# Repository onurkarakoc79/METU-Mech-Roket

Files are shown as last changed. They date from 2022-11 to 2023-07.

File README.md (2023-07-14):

# METU Mech Rocket Team Electronic Cards and Codes
This repository contains the electronic codes and card designs for the METU Mech Rocket Team's rocket system. The system consists of two card designs, each equipped with an Arduino Due controller.

## Communication Card
The first Arduino Due is responsible for communication and utilizes the following modules:

SX1262 LoRa module
SIM800L module
CH376S USB module
The communication card enables data transfer with the ground station. The SX1262 LoRa module and SIM800L module are used for wireless communication, while the CH376S USB module handles data storage to a USB device.

## Processor Card
The second Arduino Due is responsible for data processing and incorporates the following components:

BME280 sensor
Dallas temperature sensor
BMP180 sensor
NEO M8N GPS module
Parachute opening system (controlled by a servo and a transistor that fires the gas tank)
The processor card collects data related to humidity, temperature, altitude, and absolute location. It supports two sensors for each type of data, such as BME280 and BMP180. The collected data is processed using a Kalman filter algorithm for improved accuracy. The processed data is then transferred to the communication card via serial communication.

## Card Designs
This repository also includes the necessary files for the card designs. The provided KiCad files contain the card designs and necessary footprints. To use the designs, add the footprint files to KiCad in the appropriate manner. The card designs have been configured for use with either Arduino Due or Arduino Mega Due, based on the pin configuration.

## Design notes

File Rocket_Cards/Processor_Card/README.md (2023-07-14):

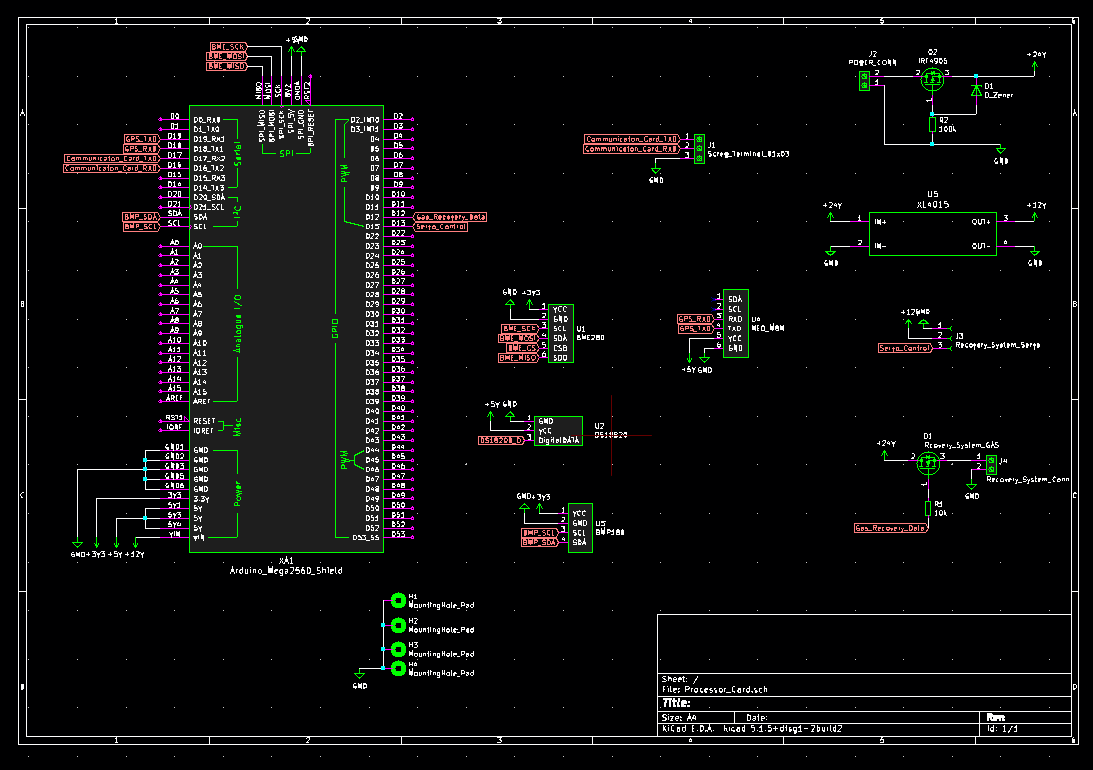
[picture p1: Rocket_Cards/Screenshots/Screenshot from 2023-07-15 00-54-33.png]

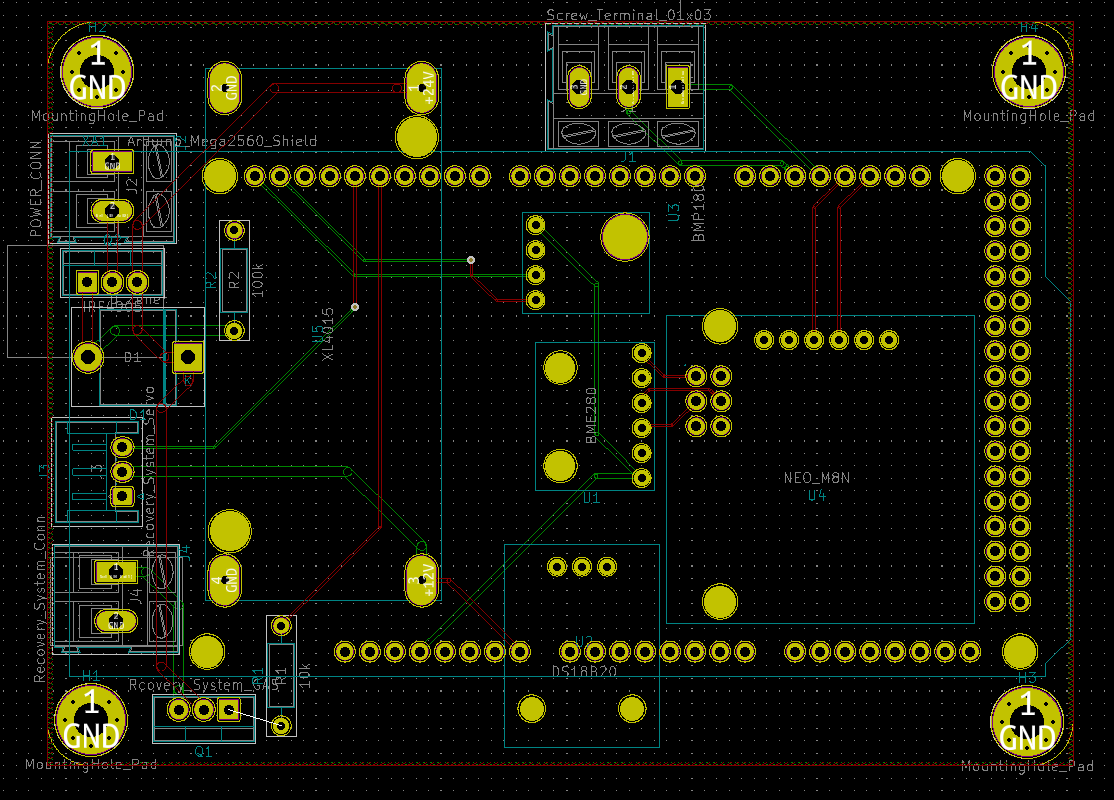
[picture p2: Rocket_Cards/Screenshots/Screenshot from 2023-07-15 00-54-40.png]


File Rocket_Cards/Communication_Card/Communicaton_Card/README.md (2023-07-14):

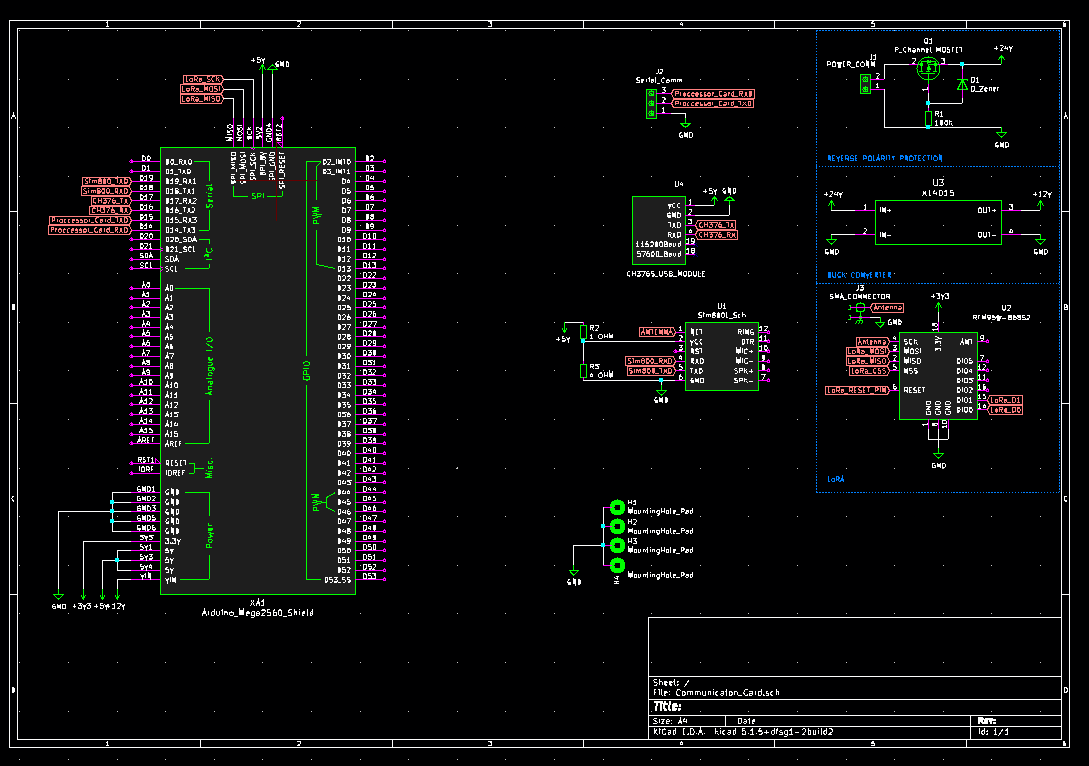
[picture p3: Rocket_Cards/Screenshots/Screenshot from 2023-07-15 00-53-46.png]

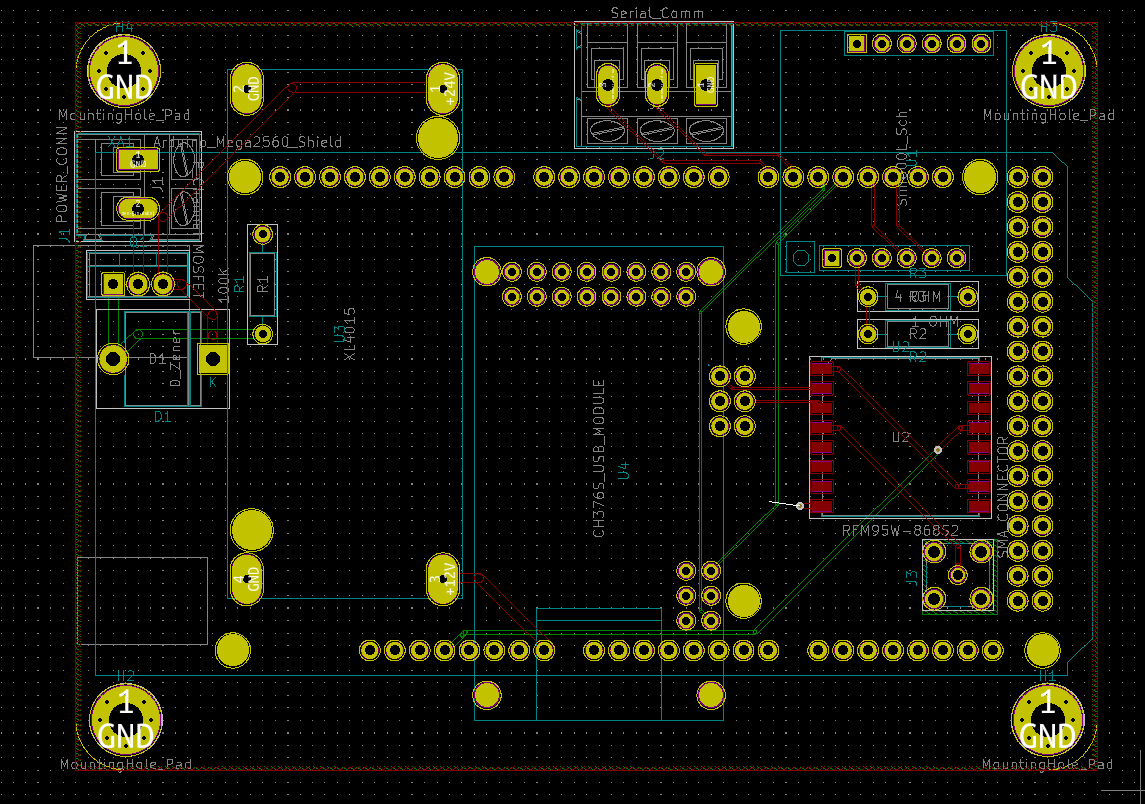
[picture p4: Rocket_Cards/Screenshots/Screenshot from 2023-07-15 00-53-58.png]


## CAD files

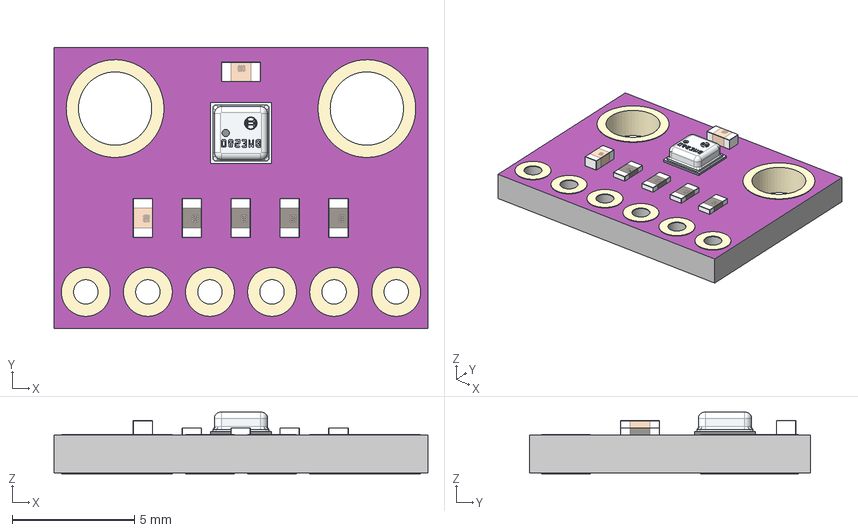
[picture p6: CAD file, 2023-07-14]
Rocket_Cards/Footprints/BME280/STEP/gy-bme280-6-pin-version-1.snapshot.2/GY-BME/P280, 6-PIN-Version v4.step
15.3 x 11.5 x 2.52 mm
Komponente1
Komponente2
Komponente3
Komponente4
Komponente5
Komponente6
Komponente7
Komponente8
Beschriftung
C0603 x 2
R0603 x 4
BME280

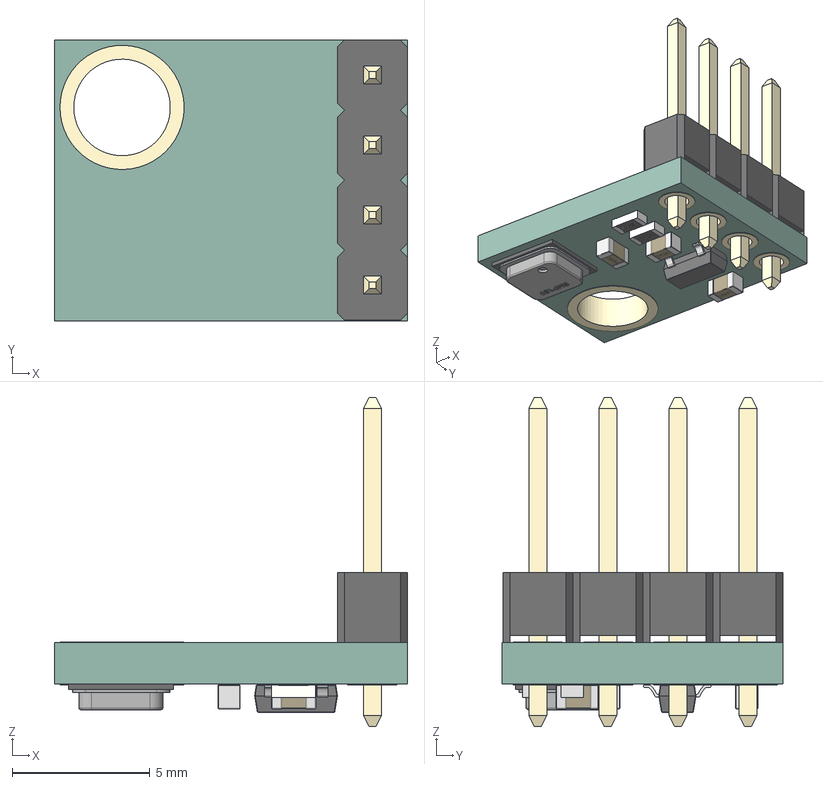
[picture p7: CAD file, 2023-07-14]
Rocket_Cards/Footprints/BMP180/STEP/bmp180-breakout-board-1.snapshot.2/BMP180 Breakout.step
12.8 x 10.2 x 11.9 mm
r-smd-0603 x 2
c-smd-0603 x 3
PinHeader
SOT23SMD v1
BMP180

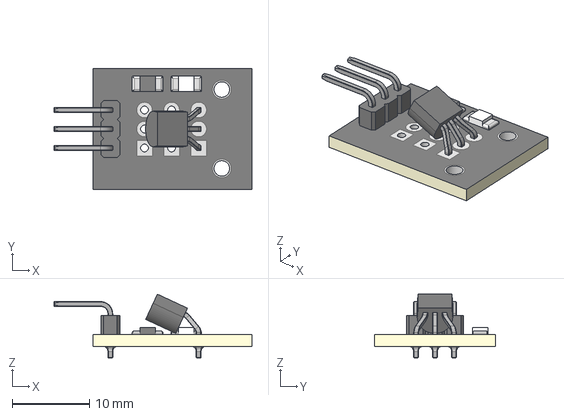
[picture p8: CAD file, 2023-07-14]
Rocket_Cards/Footprints/DS18B_Temp/STEP/temperature-sensor-module-joy-it-ky-001-ds18b20-1.snapshot.3/Temperatursensor.stp
25.6 x 15.7 x 8.24 mm

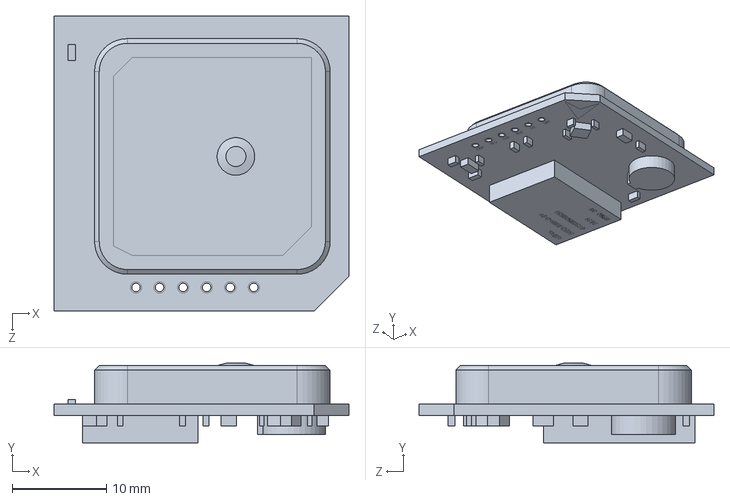
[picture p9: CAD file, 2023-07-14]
Rocket_Cards/Footprints/Neo_M8N/STEP/gps-ublox-neo-m8n-0-01-1.snapshot.1/Модуль GPS Ublox NEO-M8N-0-01.SLDPRT
31.3 x 8.44 x 31.3 mm

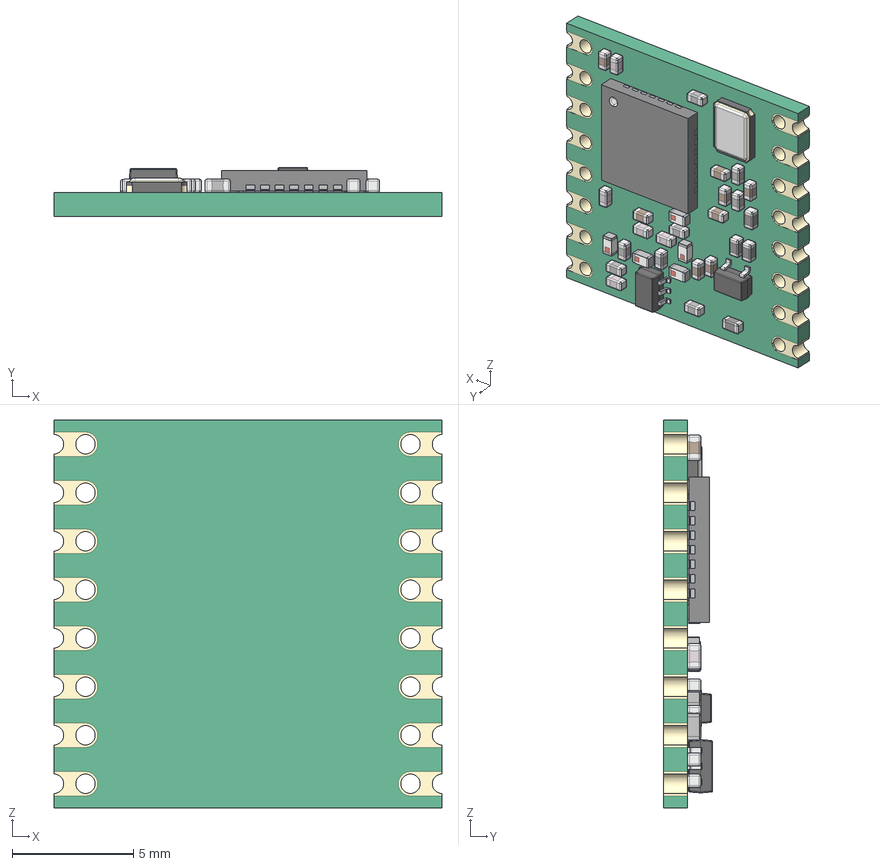
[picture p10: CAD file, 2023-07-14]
Rocket_Cards/Footprints/RFM95 STEP/rfm95-lora-radio-module-1.snapshot.1/RFM95 LoRa v15.step
16.0 x 2.04 x 16.0 mm
QFN 28
SMD Crystal
CAP 0403 x 8
CAP Ceramic 0403 x 8
Res 0403 x 4
CAP ML 0403 x 5
SOT-323
Inductor SMD 0403 x 5
SOT-363

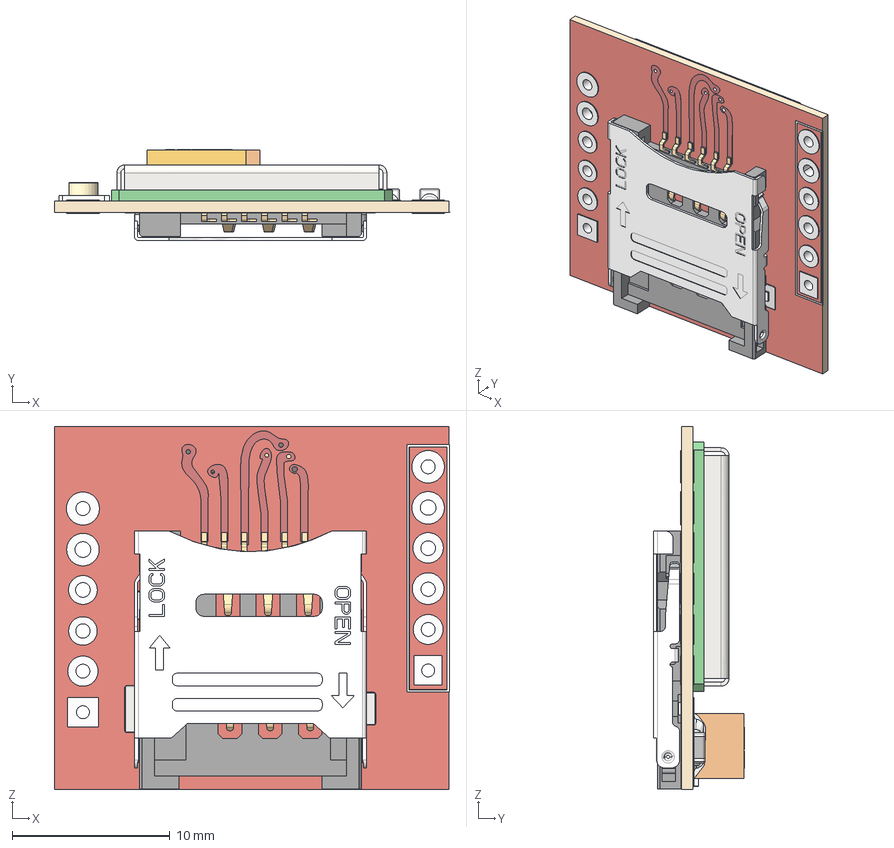
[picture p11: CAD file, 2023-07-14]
Rocket_Cards/Footprints/SIM800L-Core-Module-KiCad-Footprint-main/SIM800L v10.step
25.0 x 5.77 x 23.0 mm
PCB
Cage
CH03-HB

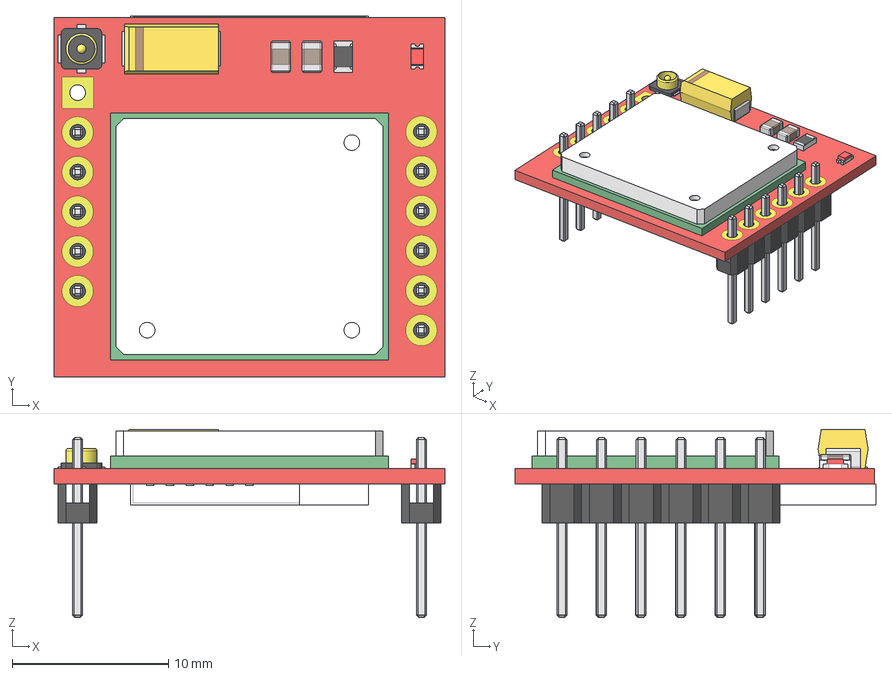
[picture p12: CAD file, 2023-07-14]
Rocket_Cards/Footprints/SIM800L-Core-Module-KiCad-Footprint-main/STEP/sim800l-9.snapshot.5/SIM800L.step
25.0 x 23.1 x 12.0 mm

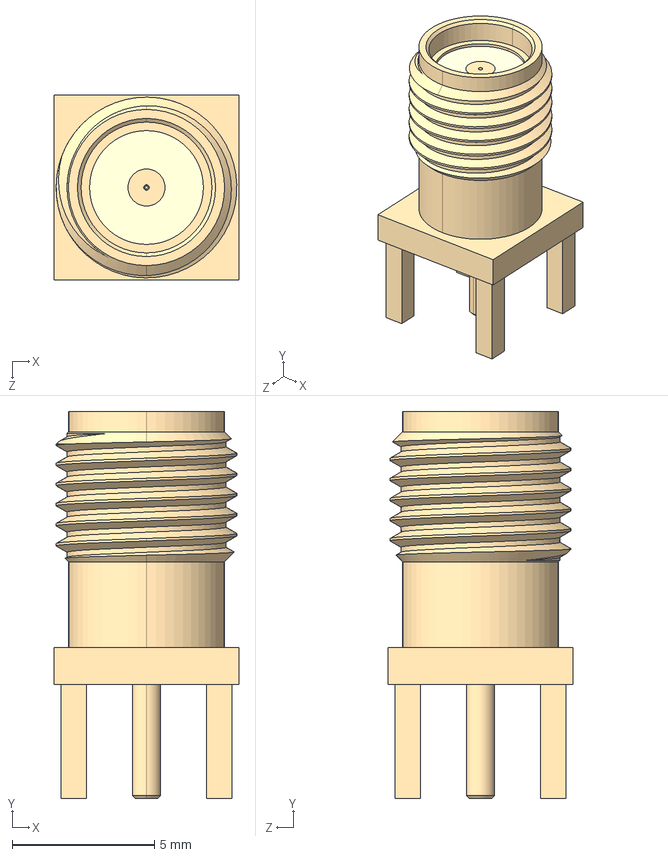
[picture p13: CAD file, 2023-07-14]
Rocket_Cards/Footprints/SMA_CONN/SMA_CONNECTOR (3)/SMA_CONNECTOR.step
6.50 x 13.6 x 6.50 mm

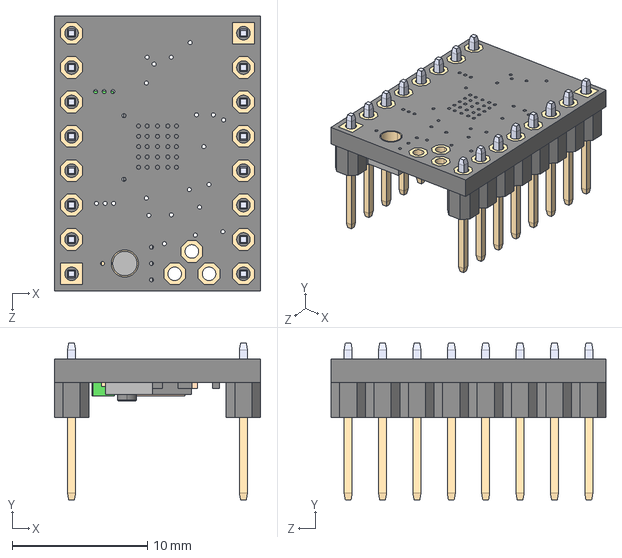
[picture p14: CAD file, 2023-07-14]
Rocket_Cards/Footprints/TMC2208_SILENTSTEPSTICK/TMC2208_SILENTSTEPSTICK.step
15.2 x 11.6 x 20.3 mm

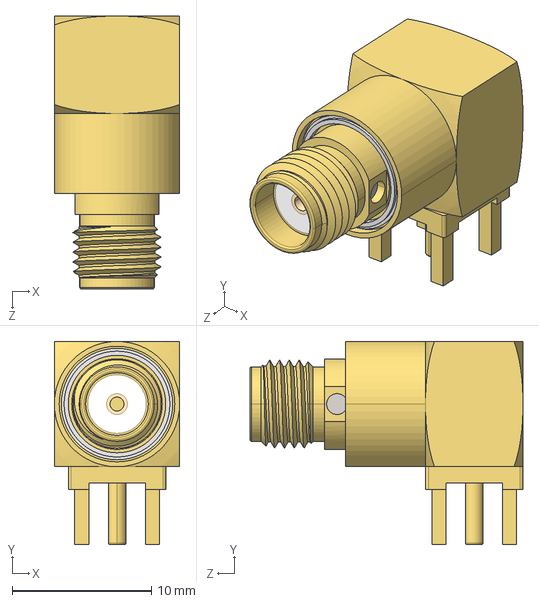
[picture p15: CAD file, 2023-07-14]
Rocket_Cards/Footprints/SMA_CONN/STEP/right-angle-sma-female-rotary-joint-pcb-mount-connector-1.snapshot.2/BM61276.STEP
9.00 x 14.6 x 19.6 mm

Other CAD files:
Rocket_Cards/Footprints/BME280/STEP/gy-bme280-6-pin-version-1.snapshot.2/GY-BME/P280, 6-PIN-Version v4.f3d
Rocket_Cards/Footprints/BMP180/STEP/bmp180-breakout-board-1.snapshot.2/BMP180 Breakout.f3d
Rocket_Cards/Footprints/DS18B_Temp/STEP/temperature-sensor-module-joy-it-ky-001-ds18b20-1.snapshot.3/Temperatursensor.igs
Rocket_Cards/Footprints/DS18B_Temp/STEP/temperature-sensor-module-joy-it-ky-001-ds18b20-1.snapshot.3/Temperatursensor.ipt

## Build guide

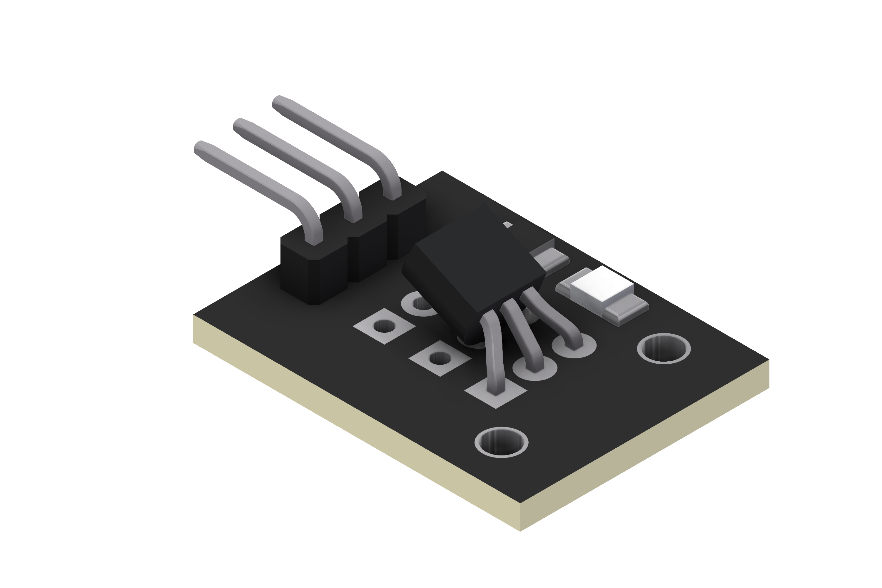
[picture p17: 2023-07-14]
Rocket_Cards/Footprints/DS18B_Temp/STEP/temperature-sensor-module-joy-it-ky-001-ds18b20-1.snapshot.3/Temperatursensor.png

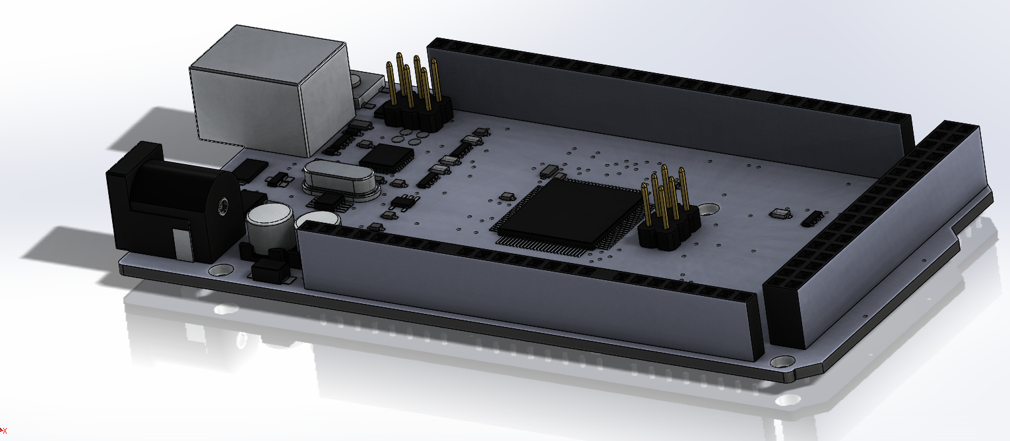
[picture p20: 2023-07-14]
Rocket_Cards/Footprints/arduino-kicad-library-master/STEP/arduino-mega-due-1.snapshot.2/Screenshot_11.png

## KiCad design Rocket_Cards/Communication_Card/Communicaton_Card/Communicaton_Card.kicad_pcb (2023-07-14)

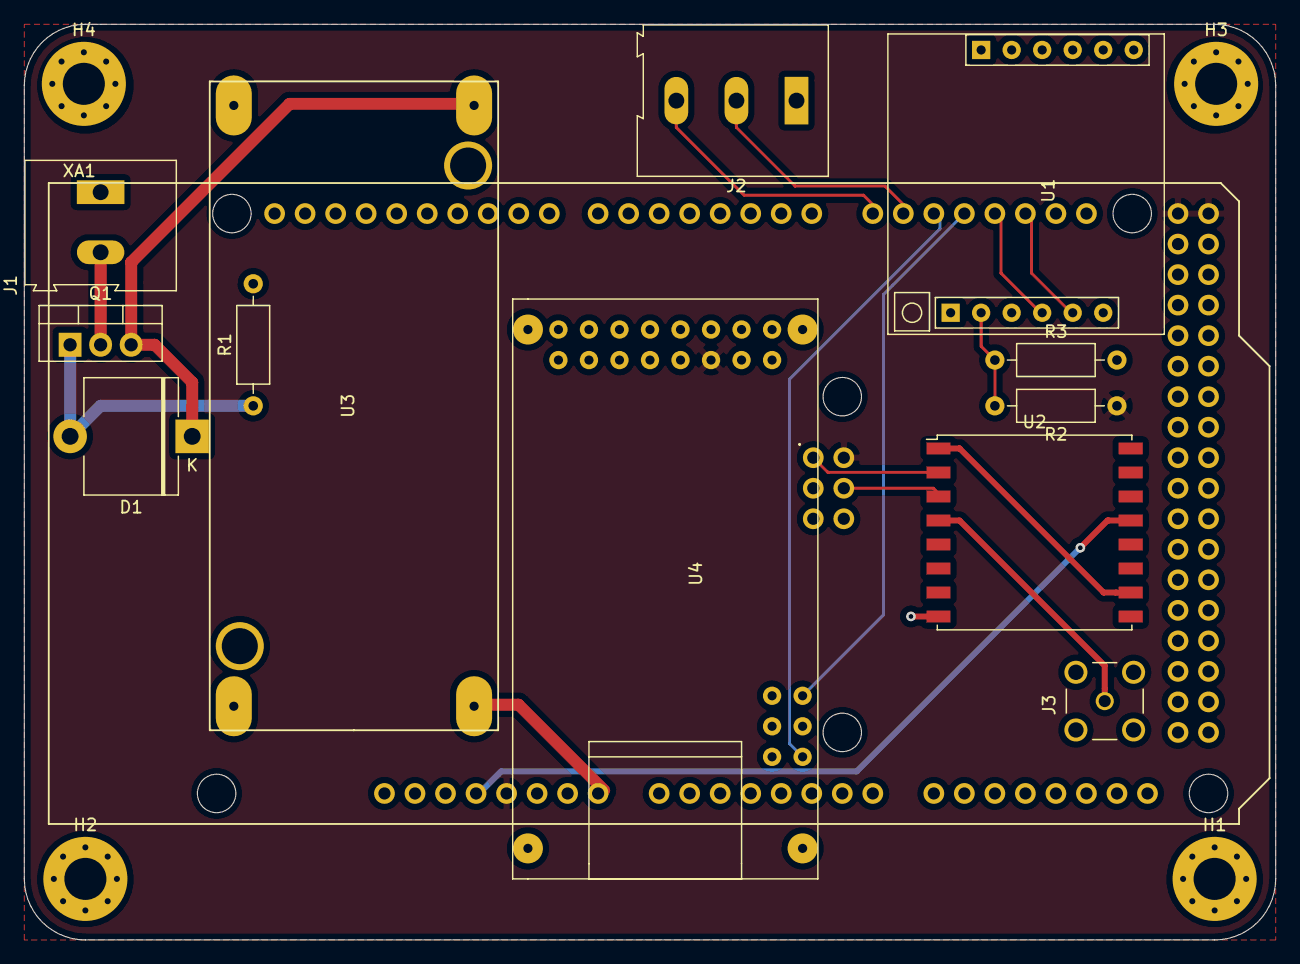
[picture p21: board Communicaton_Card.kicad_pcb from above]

Board: 2 copper layers, 104.1 x 76.2 mm, 17 parts (0 on the bottom side), 18 nets.

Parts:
D1: D_Zener; D_5KP_P10.16mm_Horizontal
H1, H2, H3, H4: MountingHole_Pad; MountingHole_3.5mm_Pad_Via
J1: POWER_CONN; TerminalBlock_Altech_AK300-2_P5.00mm
J2: Serial_Comm; TerminalBlock_Altech_AK300-3_P5.00mm
J3: SMA_CONNECTOR; LPRS_SMA_CONNECTOR
Q1: P_Channel MOSFET; TO-220-3_Vertical
R1: 100K; R_Axial_DIN0207_L6.3mm_D2.5mm_P10.16mm_Horizontal
R2: 1 OHM; R_Axial_DIN0207_L6.3mm_D2.5mm_P10.16mm_Horizontal
R3: 4 OHM; R_Axial_DIN0207_L6.3mm_D2.5mm_P10.16mm_Horizontal
U1: Sim800L_Sch; Sim800L
U2: RFM95W-868S2; HOPERF_RFM9XW_SMD
U3: XL4015; XL4015_Converter
U4: CH376S_USB_MODULE; CH376_USB_Foot
XA1: Arduino_Mega2560_Shield

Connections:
+3V3: U2.13, XA1.3V3
+5V: R2.1, U4.1, XA1.5V1, XA1.5V2, XA1.5V3, XA1.5V4
+12V: U3.3, XA1.VIN
+24V: D1.1, Q1.3, U3.1
Antenna: J3.1, U2.4
CH376_RX: U4.4, XA1.D16
CH376_TX: U4.3, XA1.D17
GND: H1.1, H2.1, H3.1, H4.1, J1.1, J2.1, J3.G1, J3.G2, J3.G3, J3.G4, R1.2, R3.2, U1.6, U2.8, U3.2, U3.4, U4.2, XA1.GND1, XA1.GND2, XA1.GND3, XA1.GND4, XA1.GND5, XA1.GND6
LoRa_MISO: U2.2, XA1.MISO
LoRa_MOSI: U2.3, XA1.MOSI
unnamed: D1.2, Q1.1, R1.1
unnamed: J1.2, Q1.2
unnamed: R2.2, R3.1, U1.2
unnamed: U2.1, U2.10
Proccessor_Card_RXD: J2.3, XA1.D14
Proccessor_Card_TXD: J2.2, XA1.D15
Sim800_RXD: U1.4, XA1.D18
Sim800_TXD: U1.5, XA1.D19

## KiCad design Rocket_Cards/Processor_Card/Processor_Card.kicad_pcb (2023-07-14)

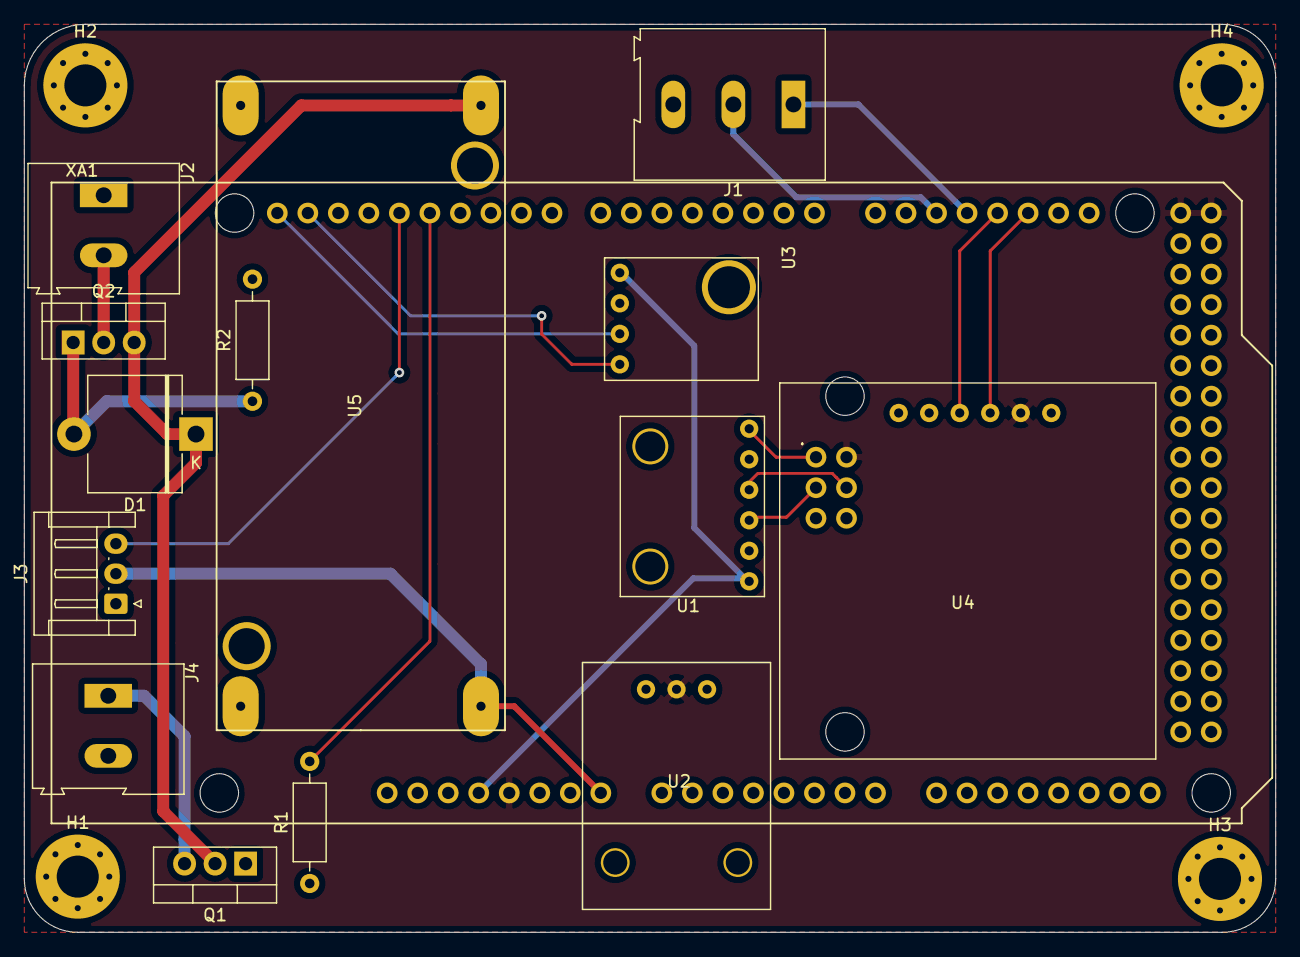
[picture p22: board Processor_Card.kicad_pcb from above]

Board: 2 copper layers, 104.1 x 75.6 mm, 19 parts (0 on the bottom side), 20 nets.

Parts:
D1: D_Zener; D_5KP_P10.16mm_Horizontal
H1, H2, H3, H4: MountingHole_Pad; MountingHole_3.5mm_Pad_Via
J1: Screw_Terminal_01x03; TerminalBlock_Altech_AK300-3_P5.00mm
J2: POWER_CONN; TerminalBlock_Altech_AK300-2_P5.00mm
J3: Recovery_System_Servo; JST_EH_S3B-EH_1x03_P2.50mm_Horizontal
J4: Recovery_System_Conn; TerminalBlock_Altech_AK300-2_P5.00mm
Q1: Rcovery_System_GAS; TO-220-3_Vertical
Q2: IRF4905; TO-220-3_Vertical
R1: 10k; R_Axial_DIN0207_L6.3mm_D2.5mm_P10.16mm_Horizontal
R2: 100k; R_Axial_DIN0207_L6.3mm_D2.5mm_P10.16mm_Horizontal
U1: BME280; BME280_3.3
U2: DS18B20
U3: BMP180
U4: NEO_M8N; Neo_M8N
U5: XL4015; XL4015_Converter
XA1: Arduino_Mega2560_Shield

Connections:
+3V3: U1.1, U3.1, XA1.3V3
+5V: U2.2, U4.5, XA1.5V1, XA1.5V2, XA1.5V3, XA1.5V4
+12V: J3.2, U5.3, XA1.VIN
+24V: D1.1, Q1.2, Q2.3, U5.1
BME_MISO: U1.6, XA1.MISO
BME_MOSI: U1.4, XA1.MOSI
BME_SCK: U1.3, XA1.SCK
BMP_SCL: U3.3, XA1.SCL
BMP_SDA: U3.4, XA1.SDA
Communicaton_Card_RXD: J1.2, XA1.D16
Communicaton_Card_TXD: J1.1, XA1.D17
GND: H1.1, H2.1, H3.1, H4.1, J1.3, J2.1, J3.1, J4.2, R2.2, U1.2, U2.1, U3.2, U4.6, U5.2, U5.4, XA1.GND1, XA1.GND2, XA1.GND3, XA1.GND4, XA1.GND5, XA1.GND6
GPS_RXD: U4.3, XA1.D18
GPS_TXD: U4.4, XA1.D19
Gas_Recovery_Data: R1.2, XA1.D12
unnamed: D1.2, Q2.1, R2.1
unnamed: J2.2, Q2.2
unnamed: J4.1, Q1.3
unnamed: Q1.1, R1.1
Servo_Control: J3.3, XA1.D13

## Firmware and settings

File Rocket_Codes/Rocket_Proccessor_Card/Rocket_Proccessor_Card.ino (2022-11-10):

#include <Wire.h>
#include <SPI.h>
#include <SoftSPIB.h>
#include <Adafruit_Sensor.h>
#include <Adafruit_BME280.h>
#include <HoneyWell_Pressure.h>
#include <TinyGPS++.h>
#include <MPU6050.h>
#include <I2Cdev.h>
#include <SimpleKalmanFilter.h>
#include <OneWire.h>
#include <DallasTemperature.h>




////////////////////////////////////////////////////////////////////DALLAS TEMPERTURE DEFINES BEGINS////////////////////////////////////////////////////////////////////////////////


static const uint8_t ONE_WIRE_BUS=47;
OneWire oneWire(ONE_WIRE_BUS);
DallasTemperature sensors(&oneWire);
DeviceAddress insideThermometer;
float dallasTemp;
float absoluteTemp;


////////////////////////////////////////////////////////////////////DALLAS TEMPERTURE DEFINES ENDS////////////////////////////////////////////////////////////////////////////////








//////////////////////////////////////////////////////////////////////////////GPS DEFINES START///////////////////////////////////////////////////////////////////////////////////


TinyGPSPlus gps;
static const uint32_t GPSBaud = 9600;
String gpsMessage="";


////////////////////////////////////////////////////////////////////////////////GPS DEFINES END///////////////////////////////////////////////////////////////////////////////////






///////////////////////////////////////////////////////////////////////PARACHUTE DEFINES STARTS///////////////////////////////////////////////////////////////////////////////////


static const int parachutePin=8;
static const int dt=1000;
static const int buzzerPin=37;
static const int ledPin=6;
static const int baloonPin=7;
bool isParachuteOpen=false;
unsigned long velocityTimer=millis();
int pastAltitude;
float velocity;
float threshold_Velocity_Parachute=40.0;
float threshold_Altitude=3000.0;
float threshold_Velocity_Baloon=70.0;
float maxAltitude=30000.0;
bool delayTimes(unsigned long *pasttime,int ms);
bool isOpen=false;
bool isBaloonCut=false;
int cutRopeCounter=0;
float pastVelocity=0;


/////////////////////////////////////////////////////////////////////////PARACHUTE DEFINES ENDS///////////////////////////////////////////////////////////////////////////////////






///////////////////////////////////////////////////////////////////////KALMAN FILTER DEFINES STARTS////////////////////////////////////////////////////////////////////////////////


SimpleKalmanFilter bmeKalman(1.0,1.0,0.01); //SimpleKalmanFilter(e_mea, e_est, q); e_mea: Measurement Uncertainty ,e_est: Estimation Uncertainty ,q: Process Noise
SimpleKalmanFilter honeywellKalman(0.1,1.0,0.03);
const long SERIAL_REFRESH_TIME=100;
long refresh_time;
bool bme_Error_Changed=false;
float absoluteAltitude;
float absolutePressure;


//////////////////////////////////////////////////////////////////////////KALMAN FILTER DEFINES ENDS//////////////////////////////////////////////////////////////////////////////






////////////////////////////////////////////////////////////////////////BME SPI DEFINES STARTS////////////////////////////////////////////////////////////////////////////////////


static const uint8_t BME_SCK=13;    // SCL to Pin 13 Arduino UNO
static const uint8_t BME_MISO=12;   // SDO to Pin 12
static const uint8_t BME_MOSI=11;   // SDA to Pin 11 
static const uint8_t BME_CS=5;     // CSB to Pin 10
static const uint8_t BME_Addresses=0x77;
static const float SEALEVELPRESSURE_HPA=1013.25;
Adafruit_BME280 bme(BME_CS); // hardware SPI
float bmeData[4]; //temp,pres,alt,hum
bool bmeEnable=true;
void bmeReadData(float *bmeDatas);
void bmePrintData(float *bmeDatas);
void bmeBegin(uint8_t addr);


////////////////////////////////////////////////////////////////////////////BME SPI DEFINES ENDS//////////////////////////////////////////////////////////////////////////////////






////////////////////////////////////////////////////////////////////////HONEYWELL PRESSURE DEFINES STARTS/////////////////////////////////////////////////////////////////////////


static const uint8_t HONEY_RESET_PIN=4;
unsigned long honeywellTimer=millis();
bool honeyEnable=true;
HoneyWell honey;
void honeyPrintData();
void checkHoneyData();


///////////////////////////////////////////////////////////////////////////// HONEYWELL PRESSURE DEFINES END//////////////////////////////////////////////////////////////////////






//////////////////////////////////////////////////////////////////////////SERIAL CONNECTION DEFINES STARTS////////////////////////////////////////////////////////////////////////


static const uint32_t MEGABaud=9600;
String message;
char termChar='#';
char c=' ';
bool haveNewData=false;
void readMessages();
void processNewData();
String Message;


///////////////////////////////////////////////////////////////////////////SERIAL CONNECTION DEFINES ENDS/////////////////////////////////////////////////////////////////////////





















void setup() {
  // put your setup code here, to run once:
  Serial.begin(9600);
  Serial1.begin(GPSBaud);
  Serial3.begin(MEGABaud);
  
  Wire.begin();
  
  pinMode(ONE_WIRE_BUS,INPUT_PULLUP);
  pinMode(HONEY_RESET_PIN,OUTPUT);
  digitalWrite(HONEY_RESET_PIN,HIGH);
  honey.begin();

  pinMode(buzzerPin,OUTPUT);
  pinMode(ledPin,OUTPUT);
  pinMode(baloonPin,OUTPUT);
  digitalWrite(buzzerPin,LOW);
  digitalWrite(ledPin,LOW);
  digitalWrite(baloonPin,LOW);
  bmeBegin(BME_Addresses);
  estimateAltitude();
  pastAltitude=absoluteAltitude;
  
  DallasBegin();
  
  delay(1000);
}


void loop() {
  // put your main code here, to run repeatedly:
  //if(gps.failedChecksum())
  GPSCreateMessage();
  
  changeBMEaccuracy();
  bmeReadData(bmeData);
  
  
  calculateAbsoluteTemp();
  
  
  honey.takePressure();
  Serial.print(honey.pressure);
  Serial.print(" ");
  honey.takeAltitude(SEALEVELPRESSURE_HPA);
  honeyPrintData();
  checkHoneyData();
  
  estimateAltitude();
  estimatePressure();
  
   if(!isOpen){ 
      calculateVelocity();
      if(!isBaloonCut){
        cutTheBaloon();
      }
      else{
        checkFreeFaling();
      }
  }
  if(isParachuteOpen){
    openLedAndBuzzer();
  }
  
  sendMessages();
  
  delay(500);
}





















///////////////////////////////////////////////////////////////////////////GPS FUNCTIONS START///////////////////////////////////////////////////////////////////////////////////


static void GPSCreateMessage(){

  static const double LONDON_LAT = 41.508131, LONDON_LON = 27.128002;
  if (millis() > 5000 && gps.charsProcessed() < 10)
    gpsMessage+="No GPS data received: check wiring";
  
  else{
    gpsMessage+="Satellites: ";
    if(gps.satellites.isValid()){
      gpsMessage+=(String)gps.satellites.value()+" "; 
    }
    else{
      gpsMessage+="**** ";
    }
    gpsMessage+="Location: " ;
    if(gps.location.isValid()){
      gpsMessage+=(String)gps.location.lat()+" "+(String)gps.location.lng()+" ";
    }
    else{
      gpsMessage+="**** **** ";
    }
    gpsMessage+="Course: ";
    if(gps.course.isValid()){
      gpsMessage+=(String)gps.course.deg()+" ";
    }
    else{
      gpsMessage+="**** ";
    }
    gpsMessage+="Speed: ";
    if(gps.speed.isValid()){
      gpsMessage+=(String)gps.speed.kmph()+" ";
    }
    else{
      gpsMessage+="**** ";
    }
  }
  smartDelay(0);
}

static void smartDelay(unsigned long ms)
{
  unsigned long start = millis();
  do 
  {
    while (Serial1.available())  // due icin duzeldi 
      gps.encode(Serial1.read());// due icin duzeldi 
  } while (millis() - start < ms);
}


////////////////////////////////////////////////////////////////////////////GPS FUNCTIONS ENDS////////////////////////////////////////////////////////////////////////////////////






///////////////////////////////////////////////////////////////////////////BME FUNCTIONS START////////////////////////////////////////////////////////////////////////////////////

void bmeBegin(uint8_t addr){
  
  unsigned status;
  status=bme.begin(addr);
  
  if(!status){
      Serial.println("Could not find a valid BME280 sensor, check wiring, address, sensor ID!");
      Serial.print("SensorID was: 0x"); Serial.println(bme.sensorID(),16);
      Serial.print("        ID of 0xFF probably means a bad address, a BMP 180 or BMP 085\n");
      Serial.print("   ID of 0x56-0x58 represents a BMP 280,\n");
      Serial.print("        ID of 0x60 represents a BME 280.\n");
      Serial.print("        ID of 0x61 represents a BME 680.\n");
      while (1) delay(10);
  }
  else{
    Serial.println("BME Started successfully");
  }
}

void bmeReadData(float *bmeDatas){
    bmeDatas[0]=bme.readTemperature();
    if(honey.altitude>9000.0){
      bmeEnable=false;
    }
    else{ 
      bmeDatas[1]=bme.readPressure()/100.0F;
      bmeDatas[2]=bme.readAltitude(SEALEVELPRESSURE_HPA);
      bmeDatas[2]=bmeKalman.updateEstimate(bmeDatas[2]);
      bmeDatas[1]=bmeKalman.updateEstimate(bmeDatas[1]);
      bmeEnable=true;
    }
    bmeDatas[3]=bme.readHumidity();
}

void bmePrintData(float *bmeDatas){
    
    Serial.print("Temperature = ");
    Serial.print(bmeData[0]);
    Serial.println(" °C");

    Serial.print("Pressure = ");

    Serial.print(bmeData[1]);
    Serial.println(" hPa");
    Serial.print("Approx. Altitude = ");
    Serial.print(bmeData[2]);
    Serial.print(" m  ");

    Serial.print("Humidity = ");
    Serial.print(bmeData[3]);
    Serial.println(" %");

    Serial.println();
}

////////////////////////////////////////////////////////////////////////////BME FUNCTIONS END/////////////////////////////////////////////////////////////////////////////////////






//////////////////////////////////////////////////////////////////HONEYWELL PRESSURE FUNCTIONS START//////////////////////////////////////////////////////////////////////////////


void honeyPrintData(){
  
  float hpa=honey.convertTohPA();
  Serial.print(honey.altitude);
  Serial.print("  meter  ");
}

void checkHoneyData(){
  if(isnan(honey.altitude)){
    digitalWrite(HONEY_RESET_PIN,LOW);
    delayTimes(&honeywellTimer,10);
    digitalWrite(HONEY_RESET_PIN,HIGH);
    honeyEnable=false;
  }
  else{
    honeyEnable=true;
  }
}


/////////////////////////////////////////////////////////////////////HONEYWELL PRESSURE FUNCTIONS END/////////////////////////////////////////////////////////////////////////////






///////////////////////////////////////////////////////////////////////KALMAN FILTER FUNCTIONS STARTS/////////////////////////////////////////////////////////////////////////////


void changeBMEaccuracy(){
  if(absoluteTemp<0){
    bmeKalman.setMeasurementError(1.7);
    bme_Error_Changed=true;
  }
  else if(bme_Error_Changed==true && absoluteTemp>0){
    bmeKalman.setMeasurementError(1.0);
    bme_Error_Changed=false;
  }
  
}

void estimateAltitude(){
  honey.altitude=honeywellKalman.updateEstimate(honey.altitude);
  if(bmeEnable && honeyEnable){
    Serial.println("bacın");
     absoluteAltitude=(honey.altitude+bmeData[2])/2.0;
  }
  else if (!bmeEnable && honeyEnable){
    Serial.println("anan");
    absoluteAltitude=honey.altitude;
  }
  else{
    Serial.println("ninen");
    absoluteAltitude=bmeData[2];
  }
  
}

void estimatePressure(){
  honey.pressure=honey.convertTohPA();
  honey.pressure=honeywellKalman.updateEstimate(honey.pressure);
  if(bmeEnable && honeyEnable){
    absolutePressure=(honey.pressure+bmeData[1])/2.0;
  }
  else if(!bmeEnable && honeyEnable){
    absolutePressure=honey.pressure;
  }
  else{
    absolutePressure=bmeData[1];
  }
}


////////////////////////////////////////////////////////////////////////KALMAN FILTER FUNCTIONS END///////////////////////////////////////////////////////////////////////////////






///////////////////////////////////////////////////////////////////////SERIAL CONNECTION CODES STARTS/////////////////////////////////////////////////////////////////////////////


void readMessages(){
  
  if(Serial3.available()){
     c=Serial3.read();
     if(c!=termChar){
        message+=c;
     }
     else{
      message=""; //bura hatalı
      haveNewData=true;
     }
  }
}


String createMessagePackage(){
  String message="";
  message="Temperture: "+(String)absoluteTemp;
  message+=" Pressure: "+(String)absolutePressure;
  message+=" Humidity: "+(String)bmeData[3];
  message+=" Altitude: "+(String)absoluteAltitude;
  message+=" Velocity vertical: "+(String)velocity+" ";
  message+=gpsMessage;
  message+="\n";
  gpsMessage="";
  return message+'#';
}

void sendMessages(){
  Message=createMessagePackage(); 
  Serial3.print(Message);
}


///////////////////////////////////////////////////////////////////////SERIAL CONNECTION CODES ENDS///////////////////////////////////////////////////////////////////////////////









////////////////////////////////////////////////////////////////////////PARACHUTE FUSE CODE STARTS///////////////////////////////////////////////////////////////////////////////


bool delayTimes(unsigned long *pasttime,int ms){
  if(millis()-*pasttime>=ms){
    *pasttime=millis();
    return true;
  }
  else{
    return false;
  }
}

void calculateVelocity(){
   if(delayTimes(&velocityTimer,dt)){
    velocity=(absoluteAltitude-pastAltitude); 
    pastAltitude=absoluteAltitude;
  }
}

void checkFreeFaling(){
  if(velocity<0.0 && abs(velocity)>threshold_Velocity_Parachute && absoluteAltitude<threshold_Altitude){
    digitalWrite(parachutePin,HIGH);
    isParachuteOpen=true;
  }
}

void openLedAndBuzzer(){
  isOpen=true;
  //Serial.print(" LED HIGH");
  //Serial.println("  BUZZER HIGH");
  digitalWrite(ledPin,HIGH);
  digitalWrite(buzzerPin,HIGH);
}

void cutTheBaloon(){
  if(absoluteAltitude>maxAltitude || cutRopeCounter>5|| absoluteTemp<-40.0){
    digitalWrite(baloonPin,HIGH);
    isBaloonCut=true;
    
    /*Serial.println("         ");
    Serial.println("Baloon Ropes Cut");
    Serial.println("Baloon Ropes Cut");
    Serial.println("  ");*/
    
  }
  if(velocity!=pastVelocity){
      
    if(velocity<0.0 && abs(velocity)>threshold_Velocity_Baloon){
      cutRopeCounter++;
    }
    else{
      cutRopeCounter=0;
    }
    pastVelocity=velocity;
  }
 
}


///////////////////////////////////////////////////////////////////////////PARACHUTE FUSE CODE ENDS///////////////////////////////////////////////////////////////////////////////







////////////////////////////////////////////////////////////////////DALLAS TEMPERTURE FUNCTIONS BEGINS////////////////////////////////////////////////////////////////////////////

void calculateAbsoluteTemp(){
  sensors.requestTemperatures();
  dallasTemp= sensors.getTempC(insideThermometer);
  absoluteTemp=(dallasTemp+bmeData[0])/2.0;
}

void DallasBegin(){
  
  Serial.println("Dallas Temperature IC Control Library Demo");

  // locate devices on the bus
  Serial.print("Locating devices...");
  sensors.begin();
  Serial.print("Found ");
  Serial.print(sensors.getDeviceCount(), DEC);
  Serial.println(" devices.");

  // report parasite power requirements
  Serial.print("Parasite power is: "); 
  if (sensors.isParasitePowerMode()) Serial.println("ON");
  else Serial.println("OFF");
  
  
  if (!sensors.getAddress(insideThermometer, 0)) Serial.println("Unable to find address for Device 0"); 
  Serial.print("Device 0 Address: ");
  printAddress(insideThermometer);
  Serial.println();

  // set the resolution to 9 bit (Each Dallas/Maxim device is capable of several different resolutions)
  sensors.setResolution(insideThermometer, 9);
 
  Serial.print("Device 0 Resolution: ");
  Serial.print(sensors.getResolution(insideThermometer), DEC); 
  Serial.println();
}

void printTemperature(DeviceAddress deviceAddress)
{
  // method 1 - slower
  //Serial.print("Temp C: ");
  //Serial.print(sensors.getTempC(deviceAddress));
  //Serial.print(" Temp F: ");
  //Serial.print(sensors.getTempF(deviceAddress)); // Makes a second call to getTempC and then converts to Fahrenheit

  // method 2 - faster
  float tempC = sensors.getTempC(deviceAddress);
  if(tempC == DEVICE_DISCONNECTED_C) 
  {
    Serial.println("Error: Could not read temperature data");
    return;
  }
  Serial.print("Temp C: ");
  Serial.print(tempC);
  Serial.print(" Temp F: ");
  Serial.println(DallasTemperature::toFahrenheit(tempC)); // Converts tempC to Fahrenheit
}

void printAddress(DeviceAddress deviceAddress)
{
  for (uint8_t i = 0; i < 8; i++)
  {
    if (deviceAddress[i] < 16) Serial.print("0");
    Serial.print(deviceAddress[i], HEX);
  }
}


///////////////////////////////////////////////////////////////////DALLAS TEMPERTURE FUNCTIONS ENDS////////////////////////////////////////////////////////////////////////////////

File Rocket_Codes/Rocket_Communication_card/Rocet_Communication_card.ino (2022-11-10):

#include <Wire.h>
#include <SPI.h>
#include <LoRa.h>
#include <Ch376msc.h>


/////////////////////////////////////////////////////////////////////////Timers Defines///////////////////////////////////////////////////////////////////////////////////////////


unsigned long GPRStimer=millis();



//////////////////////////////////////////////////////////////////////////TIMER DEFINES///////////////////////////////////////////////////////////////////////////////////////////





//////////////////////////////////////////////////////////////////////USB FLASH DISK DEFINES START////////////////////////////////////////////////////////////////////////////////


Ch376msc flashDrive(Serial2, 115200); // Ch376 object with hardware Serial2 on arduino mega baudrate: 9600, 19200, 57600, 115200
static char datafilename[]="deneme.TXT";


///////////////////////////////////////////////////////////////////////USB FLASH DISK DEFINES ENDS////////////////////////////////////////////////////////////////////////////////






//////////////////////////////////////////////////////////////////////SERIAL COMMUNICATON DEFINES START///////////////////////////////////////////////////////////////////////////


static const uint32_t DUEBaud=9600;
char c="";
String message;
String fmessage;
const int messagelength=300;
char messagearray[messagelength];
char termChar='#';
bool haveNewData=false;


////////////////////////////////////////////////////////////////////////SERIAL COMMMUNICATION DEFINES END/////////////////////////////////////////////////////////////////////////






//////////////////////////////////////////////////////////////////////////////LORA DEFINES STARTS////////////////////////////////////////////////////////////////////////////////

bool loraStatus=true;

///////////////////////////////////////////////////////////////////////////////LORA DEFINES ENDS/////////////////////////////////////////////////////////////////////////////////









void setup() {
  // put your setup code here, to run once:
  Serial.begin(9600);
  Serial1.begin(DUEBaud);//GPRS
  
  //Serial3.begin(SATCOMBaud);
  
  flashDriveBegin(datafilename);
  //LoRaBegin(-1,-1);
  
}

void loop() {
  // put your main code here, to run repeatedly:
  
  
  readMessages();
  if(haveNewData){
    fmessage.toCharArray(messagearray,messagelength);
    if(checkFlashDrive()){
      flashWriteToFile(datafilename,messagearray);
    }
    Serial.print(fmessage);
    haveNewData=false;
  }

  if(delayTimes(&GPRStimer,100000)){
    //GPRS çalışsın
    Serial.println("GPRS message sended");
    
  }
 
 
  
  /*SAKIN DELAY ATMA SIÇARIM AĞZINA*/
  
}









//////////////////////////////////////////////////////////////////////SERIAL COMMUNICATION FUNCTIONS START////////////////////////////////////////////////////////////////////////


void readMessages(){
  
  if(Serial1.available()){
     c=Serial1.read();
     if(c!=termChar){
        message+=c;
     }
     else{
      fmessage=message;
      message="";
      haveNewData=true;
     }
  }
}


///////////////////////////////////////////////////////////////////////SERIAL COMMUNICATION FUNCTIONS END/////////////////////////////////////////////////////////////////////////






////////////////////////////////////////////////////////////////////////////////TIMER////////////////////////////////////////////////////////////////////////////////////////////


bool delayTimes(unsigned long *pasttime,int ms){
  if(millis()-*pasttime>=ms){
    *pasttime=millis();
    return true;
  }
  else{
    return false;
  }
}


//////////////////////////////////////////////////////////////////////////////TIMER/////////////////////////////////////////////////////////////////////////////////////////////






////////////////////////////////////////////////////////////////LORA COMMUNICATON FUNCTIONS STARTS////////////////////////////////////////////////////////////////////////////////


static void LoRaBegin(int spreedingfactor,long bandwith){
  if(!LoRa.begin(915E6)){
    Serial.println("Starting LoRa failed!");
    loraStatus=false;
  }
  if(!(spreedingfactor==-1 && bandwith==-1)){
    LoRa.setSpreadingFactor(spreedingfactor);
    LoRa.setSignalBandwidth(bandwith);
  }
}

static void LoRaSendData(String msg){
  LoRa.beginPacket();
  LoRa.print(msg);
  LoRa.endPacket();
}


////////////////////////////////////////////////////////////////////LORA COMMUNICATON FUNCTIONS ENDS/////////////////////////////////////////////////////////////////////////////






//////////////////////////////////////////////////////////////////////USB FLASH DISK FUNCTIONS STARTS/////////////////////////////////////////////////////////////////////////////


void flashDriveBegin(char * filename){
  flashDrive.init();
  Serial.println("Hello madafaka flash drive initilized");
  if(!checkFlashDrive()){
    Serial.println("Attach flash drive first!");
    while(!checkFlashDrive()){
      ;
    }
    Serial.println("Flash Drive attached");
  }
  flashDeleteFile(filename);
  flashCreateFile(filename);
}

bool checkFlashDrive(){
  
  
  flashDrive.checkIntMessage();  //this fucntion must be called for getdevicestatus function
  if(flashDrive.getDeviceStatus()){
    
    return true;
  } 
  else {
    return false;
  }

  
}

void flashWriteToFile(char* filename,char* message){
  flashDrive.setFileName(filename);
  if(flashDrive.openFile()==ANSW_USB_INT_SUCCESS){
    flashDrive.moveCursor(CURSOREND);
  }
  if(flashDrive.getFreeSectors()){
    flashDrive.writeFile(message,strlen(message));
  }
  else{
    Serial.println("Disk Full");
  }
  flashDrive.closeFile();
}

void flashCreateFile(char* filename){
  flashDrive.setFileName(filename);
  flashDrive.openFile();
  flashDrive.writeFile("Baloon Sensors Data:\n",strlen("Baloon Sensors Data:\n"));
  flashDrive.closeFile();
}

void flashDeleteFile(char* filename){
  flashDrive.setFileName(filename);
  flashDrive.deleteFile();
}

////////////////////////////////////////////////////////////////// USB FLASH DISK FUNCTIONS ENDS ////////////////////////////////////////////////////////////////////////////////






////////////////////////////////////////////////////////////////// GPRS FUNCTIONS STARTS /////////////////////////////////////////////////////////////////////////////////////////


////////////////////////////////////////////////////////////////// GPRS FUNCTIONS ENDS   ////////////////////////////////////////////////////////////////////////////////////////////
